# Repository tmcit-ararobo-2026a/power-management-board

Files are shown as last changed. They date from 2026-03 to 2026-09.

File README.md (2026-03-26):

# 電源管理基板
ロボットのバッテリー管理・駆動系電源遮断を行う基板を作成

## 目次

1. [概要](#1-概要)
2. [コントリビューション](#2-コントリビューション)
3. [ライセンス](#3-ライセンス)

## 1. 概要
バッテリー管理コスト削減および駆動系電源遮断を目的とする。
STM32G431K8T6を搭載し、各機能を統括する。

### 機能
- ソフトスタート機能
- 過電圧保護機能
- 電流計測機能
- 制御系・駆動系の絶縁
- 非常停止機能
- バルクコンデンサ

### ソフトスタート機能
突入電流を軽減する目的でソフトスタート機能を実装する。
C2およびR2によって調整される。

100msぐらいで電圧が上昇する計算。
コンデンサの充電時の突入電流を軽減できる。

### 過電圧保護機能
モーターの回生電圧による過電圧時にバッテリーを遮断する。
バッテリーの保護を目的とする。

バルクコンデンサによる軽減および、LM74502QDDFRQ1（過電圧保護機能付き車載用低 IQ 逆極性保護コント
ローラ）による過電圧保護が有効。

過電圧保護は25V前後で働く。
抵抗R3およびR4による分圧で決まる。

### 電流計測機能
バッテリーから出力される電流値を測る。
バッテリーの状態を判断したり、ロボットの総消費電流を分析する目的である。

### 制御系・駆動系の絶縁
制御系と駆動系の絶縁はフォトカプラによって実装。
スイッチ部もSTM32等を保護する観点および、グランドのループを解消する目的で絶縁。

### 非常停止機能
ダブルMOSFETによる完全な駆動系電源遮断を実現。
遠隔非常停止との連携や物理的な非常停止スイッチをJ7/J8間に接続することで非常停止が作動する。

### バルクコンデンサ
モーターの回生電圧を抑え、過渡的な電流上昇時の電源安定を目的とし、2700uFの電解コンデンサを出力部に搭載。

UHE1H272MHDであり、ひとつあたりのリップル電流は3.8Aであるので、合計7.6Aの過渡的な電流増大を軽減できる。

## 2. コントリビューション

[CONTRIBUTING.md](./CONTRIBUTING.md) を参照してください。

## 3. ライセンス

本リポジトリは [MITライセンス](./LICENSE) のもとで公開されています。

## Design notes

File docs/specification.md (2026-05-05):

## 仕様書

バッテリー管理コスト削減および駆動系電源遮断を目的とする電源管理基板である。

### 機能
- ソフトスタート機能
- 過電圧保護機能
- 電流計測機能
- 制御系・駆動系の絶縁
- 非常停止機能
- バルクコンデンサ

### ソフトスタート機能
突入電流を軽減する目的でソフトスタート機能を実装する。
C2およびR2によって調整される。

100msぐらいで電圧が上昇する計算。
コンデンサの充電時の突入電流を軽減できる。

### 過電圧保護機能
モーターの回生電圧による過電圧時にバッテリーを遮断する。
バッテリーの保護を目的とする。

バルクコンデンサによる軽減および、LM74502QDDFRQ1（過電圧保護機能付き車載用低 IQ 逆極性保護コント
ローラ）による過電圧保護が有効。

過電圧保護は25V前後で働く。
抵抗R3およびR4による分圧で決まる。

### 電流計測機能
バッテリーから出力される電流値を測る。
バッテリーの状態を判断したり、ロボットの総消費電流を分析する目的である。

### 制御系・駆動系の絶縁
制御系と駆動系の絶縁はフォトカプラによって実装。
スイッチ部もSTM32等を保護する観点および、グランドのループを解消する目的で絶縁。

### 非常停止機能
ダブルMOSFETによる完全な駆動系電源遮断を実現。
遠隔非常停止との連携や物理的な非常停止スイッチをJ7/J8間に接続することで非常停止が作動する。

### バルクコンデンサ
モーターの回生電圧を抑え、過渡的な電流上昇時の電源安定を目的とし、2700uFの電解コンデンサを出力部に搭載。

UHE1H272MHDであり、ひとつあたりのリップル電流は3.8Aであるので、合計7.6Aの過渡的な電流増大を軽減できる。

### LEDインジケータ
|名称|色|仕様|
|:-:|:-:|:-:|
|LED1|赤|メイン処理ループにて点滅|
|LED2|赤|過電流保護|
|LED3|青|電源供給中|
|LED4|緑|初期化済み（CAN疎通確認）|

### 状態
1. 起動時
遠隔非常停止は無効化され、EMS-INとEMS-OUTを接続することで駆動系はONになる。

2. 遠隔非常停止有効時

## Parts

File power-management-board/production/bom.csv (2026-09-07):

Designator | Footprint | Quantity | Value | LCSC Part #
C10 | 0603 | 1 | 10uf
C11, C12, C13, C14, C19, C20, C21, C25, C26, C5, C6, C7, C8 | 0603 | 13 | 0.1uf
C15, C16, C17, C18 | 0603 | 4 | 1nf
C22 | 0603 | 1 | 0.47uf
C23 | 0603 | 1 | 10nf
C24 | 0603 | 1 | 0.22uf
C3, C4 | CP_Radial_D18.0mm_P7.50mm | 2 | 2700uf
C9 | 0603 | 1 | 1uf
D10, D4, D5, D7, D8, D9 | SOD-123FL | 6 | SS2040FL
D11, D12, D13, D14, D15, D16, D17, D18, D19, D2, D20, D21, D22, D24, D3, D6 | 0603 | 16 | LED
D23, D25, D26, D27, D28 | Diode_US2H | 5 | CUHS20S60
F2 | 0603 | 1 | FCC16501ABTP
IC2 | SOIC127P1105X220-8N | 1 | TLP7820_TP4,E
IC3 | SOIC127P600X175-8N | 1 | MCP2562
IC4 | SOP50P490X110-10N | 1 | LTC4368IMS-2#PBF
J1, J8 | AMASS_XT60-F_1x02_P7.20mm_Vertical | 2 | Conn_01x02
J2, J7 | AMASS_XT60-M_1x02_P7.20mm_Vertical | 2 | Conn_01x02
J3, J4 | JST_XH_S4B-XH-A_1x04_P2.50mm_Horizontal | 2 | Conn_01x04
J5 | PinHeader_1x04_P2.54mm_Vertical | 1 | Conn_01x04_Pin
J6 | TestPoint_2Pads_Pitch2.54mm_Drill0.8mm | 1 | Conn_01x02_Pin
J9 | AMASS_MR30PW-M_1x03_P3.50mm_Horizontal | 1 | Conn_01x03
JP1 | PinHeader_1x02_P2.54mm_Vertical | 1 | jp
Q1, Q2 | XPQR8308QB,LXHQ | 2 | XPQR8308QB,LXHQ
R1, R10, R16, R27, R28, R29, R31, R32, R33, R34, R35, R36, R37, R38, R39, R40, R41, R42, R43, R44, R45, R5, R6, R7, R8, R9 | 0603 | 26 | 1k
R11, R12, R13, R14 | RESC11050X120N | 4 | 100Ω
R15, R19, R22 | 0603 | 3 | 100k
R18, R23, R26, R51, R52 | 0603 | 5 | 10k
R20, R21 | 0603 | 2 | 4.7k
R24 | 0603 | 1 | 120
R25 | 0603 | 1 | 1.6k
R30 | 0603 | 1 | 100
R46, R49 | 0603 | 2 | 2k
R47 | 0603 | 1 | 3k
R48 | 0603 | 1 | 143k
R53 | 0603 | 1 | 22k
RV1, RV2 | Potentiometer_Bourns_3296W_Vertical | 2 | 10k
SW1 | switch_TVAF06-A020B-R | 1 | SW_Push
SW3 | CJS1200A1 | 1 | SW_SPDT_312
TP1, TP2, TP3 | TestPoint_Loop_D1.80mm_Drill1.0mm_Beaded | 3 | TestPoint
U1, U5, U8, U9 | SOIC-4_4.55x2.6mm_P1.27mm | 4 | TLP293
U2 | DIP-6_W7.62mm_SMDSocket_SmallPads | 1 | TLP3546A
U3 | LQFP-32_7x7mm_P0.8mm | 1 | STM32G431K8Tx
U4 | SOT-23-5_HandSoldering | 1 | NJM12888F33
U6 | CZ3A07 | 1 | CZ3A07
U7 | SOT-23_Handsoldering | 1 | AP7375

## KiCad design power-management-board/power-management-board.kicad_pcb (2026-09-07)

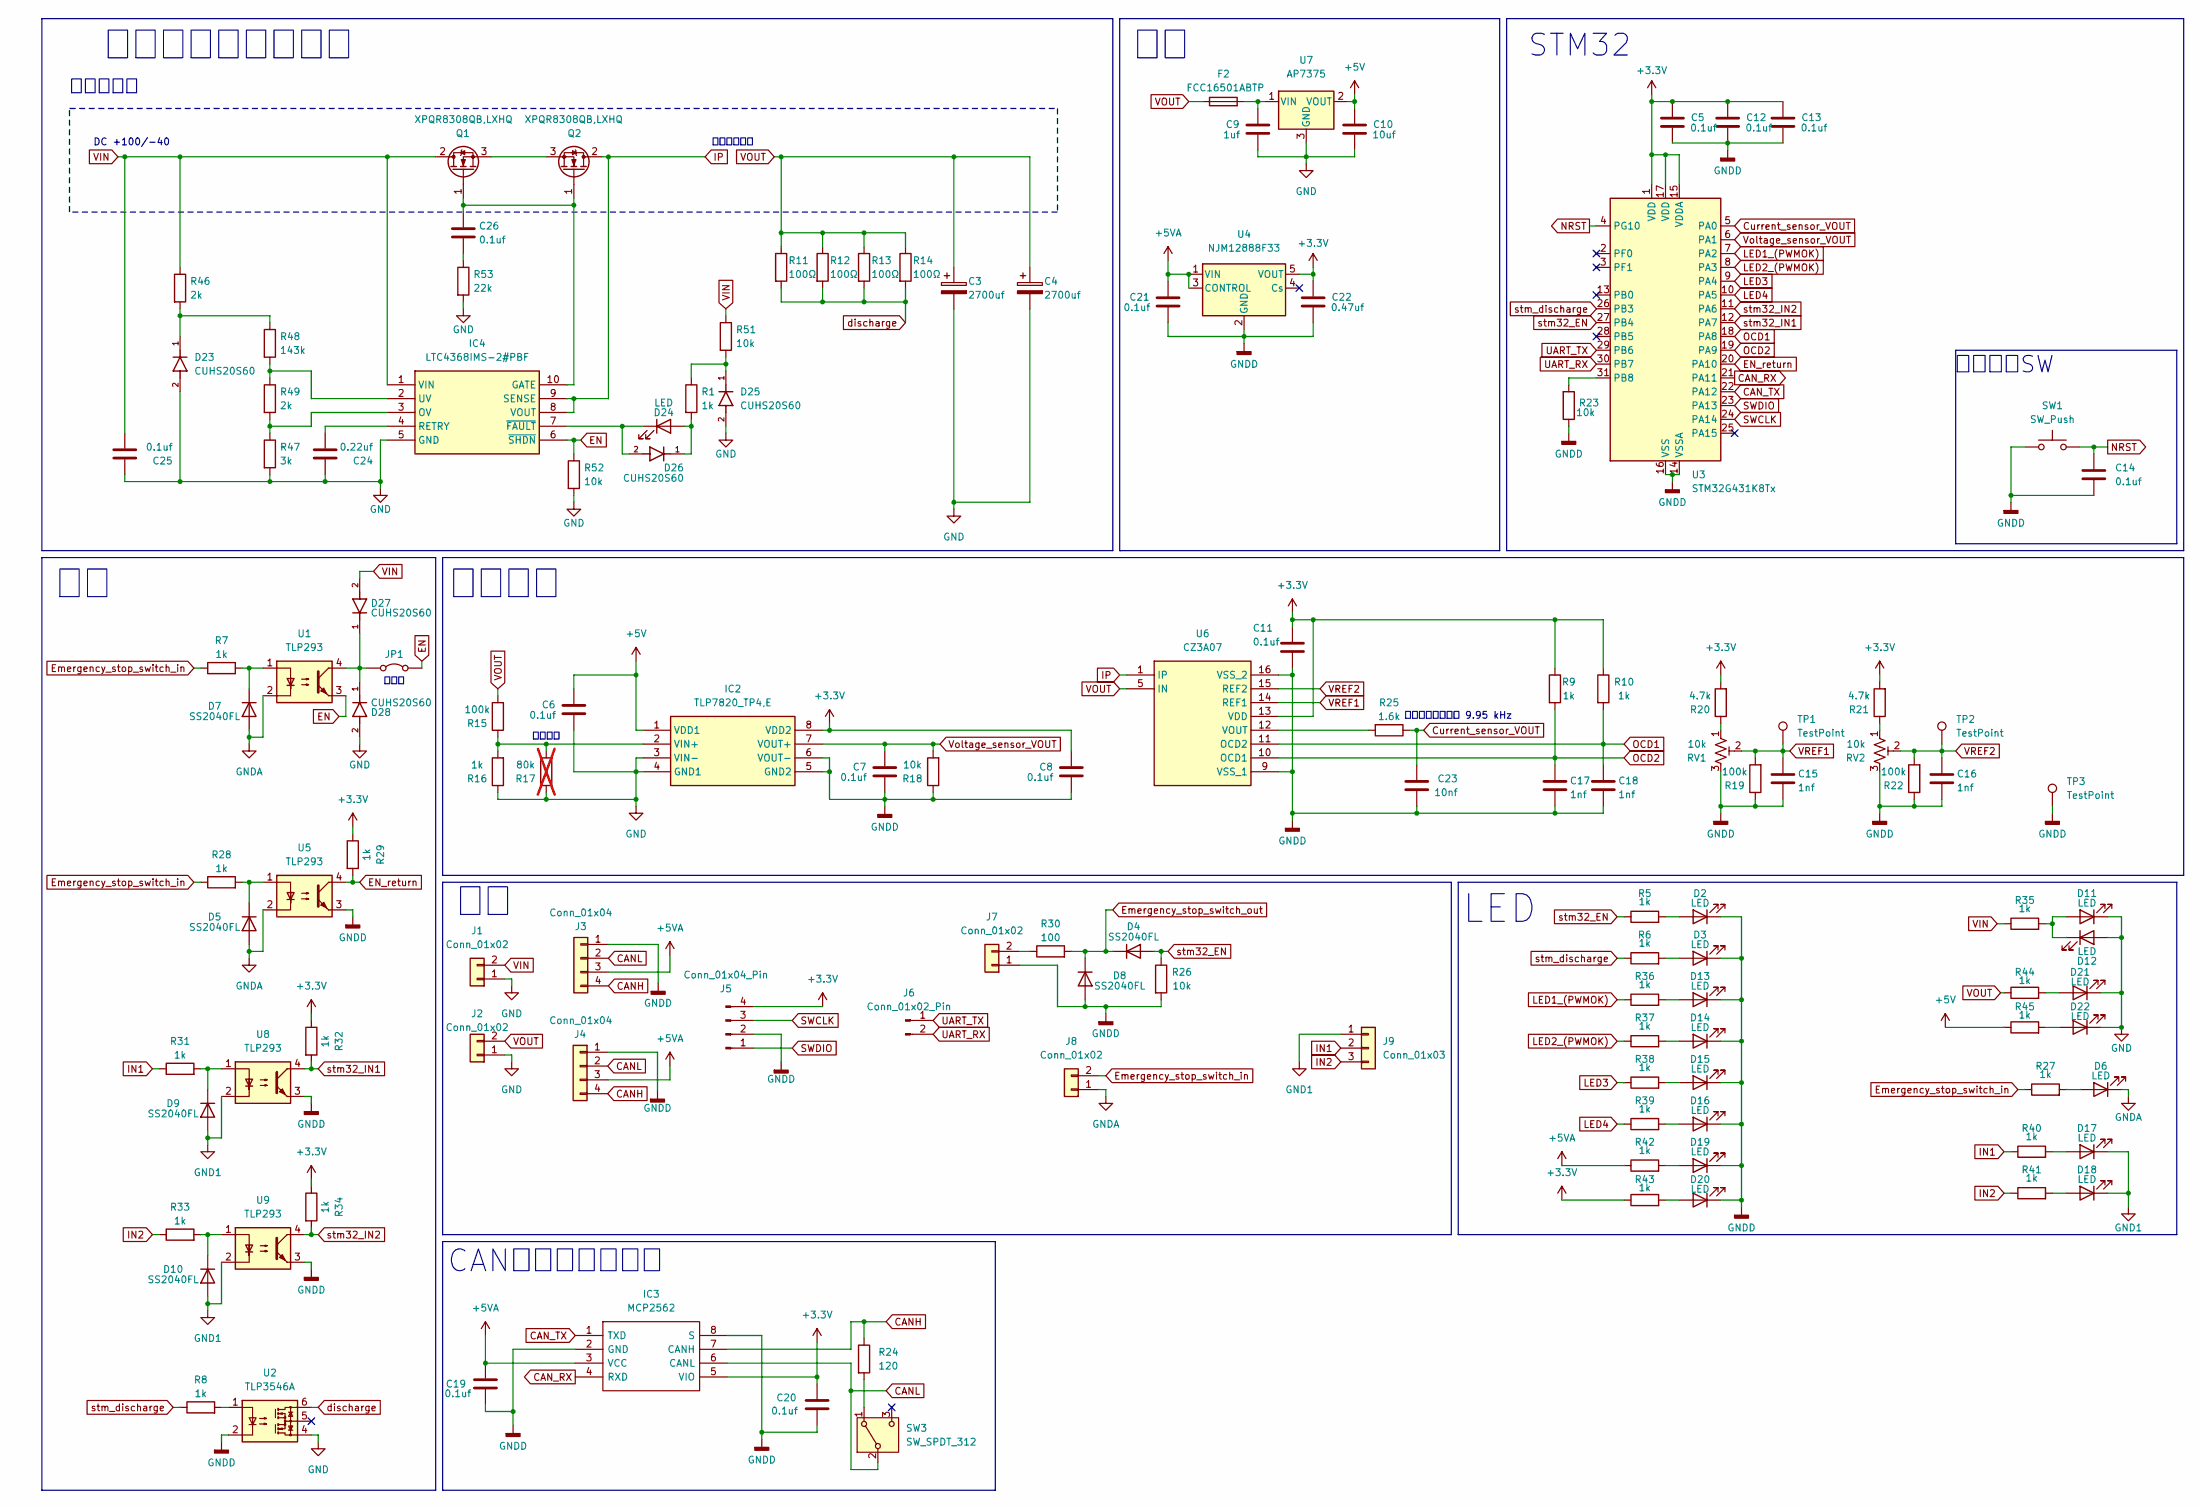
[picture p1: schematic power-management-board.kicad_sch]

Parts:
C3, C4: 2700uf; CP_Radial_D18.0mm_P7.50mm
C5, C6, C7, C8, C11, C12, C13, C14, C19, C20, C21, C25, C26: 0.1uf; C_0603_1608Metric_Pad1.08x0.95mm_HandSolder
C9: 1uf; C_0603_1608Metric_Pad1.08x0.95mm_HandSolder
C10: 10uf; C_0603_1608Metric_Pad1.08x0.95mm_HandSolder
C15, C16, C17, C18: 1nf; C_0603_1608Metric_Pad1.08x0.95mm_HandSolder
C22: 0.47uf; C_0603_1608Metric_Pad1.08x0.95mm_HandSolder
C23: 10nf; C_0603_1608Metric_Pad1.08x0.95mm_HandSolder
C24: 0.22uf; C_0603_1608Metric_Pad1.08x0.95mm_HandSolder
D2, D3, D6, D11, D12, D13, D14, D15, D16, D17, D18, D19, D20, D21, D22, D24: LED; LED_0603_1608Metric_Pad1.05x0.95mm_HandSolder
D4, D5, D7, D8, D9, D10: SS2040FL; SOD-123FL
D23, D25, D26, D27, D28: CUHS20S60; Diode_US2H; PARTREV G
F2: FCC16501ABTP; Fuse_0603_1608Metric_Pad1.05x0.95mm_HandSolder
IC2: TLP7820_TP4,E; SOIC127P1105X220-8N; Manufacturer_Part_Number LM74502QDDFRQ1
IC3: MCP2562; SOIC127P600X175-8N; Mouser Part Number 771-TJA1441AT/0Z
IC4: LTC4368IMS-2#PBF; SOP50P490X110-10N; Mouser Part Number 584-LTC4368IMS2PBF
J1, J8: Conn_01x02; AMASS_XT60-F_1x02_P7.20mm_Vertical
J2, J7: Conn_01x02; AMASS_XT60-M_1x02_P7.20mm_Vertical
J3, J4: Conn_01x04; JST_XH_S4B-XH-A_1x04_P2.50mm_Horizontal
J5: Conn_01x04_Pin; PinHeader_1x04_P2.54mm_Vertical
J6: Conn_01x02_Pin; TestPoint_2Pads_Pitch2.54mm_Drill0.8mm
J9: Conn_01x03; AMASS_MR30PW-M_1x03_P3.50mm_Horizontal
JP1: jp; PinHeader_1x02_P2.54mm_Vertical
Q1, Q2: XPQR8308QB,LXHQ
R1, R5, R6, R7, R8, R9, R10, R16, R27, R28, R29, R31, R32, R33, R34, R35, R36, R37, R38, R39, R40, R41, R42, R43, R44, R45: 1k; R_0603_1608Metric_Pad0.98x0.95mm_HandSolder
R11, R12, R13, R14: 100Ω; RESC11050X120N
R15, R19, R22: 100k; R_0603_1608Metric_Pad0.98x0.95mm_HandSolder
R17: 80k; R_0603_1608Metric_Pad0.98x0.95mm_HandSolder; not fitted
R18, R23, R26, R51, R52: 10k; R_0603_1608Metric_Pad0.98x0.95mm_HandSolder
R20, R21: 4.7k; R_0603_1608Metric_Pad0.98x0.95mm_HandSolder
R24: 120; R_0603_1608Metric_Pad0.98x0.95mm_HandSolder
R25: 1.6k; R_0603_1608Metric_Pad0.98x0.95mm_HandSolder
R30: 100; R_0603_1608Metric_Pad0.98x0.95mm_HandSolder
R46, R49: 2k; R_0603_1608Metric_Pad0.98x0.95mm_HandSolder
R47: 3k; R_0603_1608Metric_Pad0.98x0.95mm_HandSolder
R48: 143k; R_0603_1608Metric_Pad0.98x0.95mm_HandSolder
R53: 22k; R_0603_1608Metric_Pad0.98x0.95mm_HandSolder
RV1, RV2: 10k; Potentiometer_Bourns_3296W_Vertical
SW1: SW_Push; switch_TVAF06-A020B-R
SW3: SW_SPDT_312; CJS1200A1
TP1, TP2, TP3: TestPoint; TestPoint_Loop_D1.80mm_Drill1.0mm_Beaded
U1, U5, U8, U9: TLP293; SOIC-4_4.55x2.6mm_P1.27mm
U2: TLP3546A; DIP-6_W7.62mm_SMDSocket_SmallPads
U3: STM32G431K8Tx; LQFP-32_7x7mm_P0.8mm
U4: NJM12888F33; SOT-23-5_HandSoldering
U6: CZ3A07; Mouser Part Number 412-CZ3A07
U7: AP7375; SOT-23_Handsoldering

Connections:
+3.3V: C5.1, C8.1, C11.1, C12.1, C13.1, C20.1, C22.1, IC2.8 (VDD2), IC3.5 (VIO), J5.4, R9.1, R10.1, R20.2, R21.2, R29.1, R32.1, R34.1, R43.1, U3.1 (VDD), U3.15 (VDDA), U3.17 (VDD), U4.5 (VOUT), U6.13 (VDD)
+5V: C6.1, C10.1, IC2.1 (VDD1), R45.1, U7.2 (VOUT)
+5VA: C19.1, C21.1, IC3.3 (VCC), J3.3, J4.3, R42.1, U4.1 (VIN), U4.3 (CONTROL)
CANH: IC3.7 (CANH), J3.4, J4.4, R24.1
CANL: IC3.6 (CANL), J3.2, J4.2, SW3.2 (B)
CAN_RX: IC3.4 (RXD), U3.21 (PA11)
CAN_TX: IC3.1 (TXD), U3.22 (PA12)
Current_sensor_VOUT: C23.2, R25.1, U3.5 (PA0)
EN: IC4.6 (~SHDN), JP1.2 (B), R52.1, U1.3
EN_return: R29.2, U3.20 (PA10), U5.4
Emergency_stop_switch_in: J8.2, R7.1, R27.1, R28.1
Emergency_stop_switch_out: D4.1 (K), D8.1 (K), R30.2
GND: C3.2, C4.2, C6.2, C9.2, C10.2, C24.1, C25.1, D11.1 (K), D12.2 (A), D21.1 (K), D22.1 (K), D23.2, D25.2, D28.2, IC2.3 (VIN-), IC2.4 (GND1), IC4.5 (GND), J1.1, J2.1, R16.1, R17.1, R47.2, R52.2, R53.2, U2.4, U7.3 (GND)
GND1: D9.2 (A), D10.2 (A), D17.1 (K), D18.1 (K), J9.1, U8.2, U9.2
GNDA: D5.2 (A), D6.1 (K), D7.2 (A), J8.1, U1.2, U5.2
GNDD: C5.2, C7.2, C8.2, C11.2, C12.2, C13.2, C14.2, C15.2, C16.2, C17.2, C18.2, C19.2, C20.2, C21.2, C22.2, C23.1, D2.1 (K), D3.1 (K), D8.2 (A), D13.1 (K), D14.1 (K), D15.1 (K), D16.1 (K), D19.1 (K), D20.1 (K), IC2.5 (GND2), IC2.6 (VOUT-), IC3.2 (GND), IC3.8 (S), J3.1, J4.1, J5.2, J7.1, R18.1, R19.1, R22.1, R23.1, R26.2, RV1.3, RV2.3, SW1.1, TP3.1 (1_1), U2.2, U3.14 (VSSA), U3.16 (VSS), U3.32 (VSS), U4.2 (GND), U5.3, U6.9 (VSS_1), U6.16 (VSS_2), U8.3, U9.3
IN1: J9.2, R31.1, R40.1
IN2: J9.3, R33.1, R41.1
IP: IC4.8 (VOUT), IC4.9 (SENSE), Q2.2 (D), U6.1 (IP)
LED1_(PWMOK): R36.1, U3.7 (PA2)
LED2_(PWMOK): R37.1, U3.8 (PA3)
LED3: R38.1, U3.9 (PA4)
LED4: R39.1, U3.10 (PA5)
NRST: C14.1, SW1.2, U3.4 (PG10)
unnamed: C26.2, R53.1
unnamed: D2.2 (A), R5.2
unnamed: D3.2 (A), R6.2
unnamed: D5.1 (K), R28.2, U5.1
unnamed: D6.2 (A), R27.2
unnamed: D7.1 (K), R7.2, U1.1
unnamed: D9.1 (K), R31.2, U8.1
unnamed: D10.1 (K), R33.2, U9.1
unnamed: D11.2 (A), D12.1 (K), R35.2
unnamed: D13.2 (A), R36.2
unnamed: D14.2 (A), R37.2
unnamed: D15.2 (A), R38.2
unnamed: D16.2 (A), R39.2
unnamed: D17.2 (A), R40.2
unnamed: D18.2 (A), R41.2
unnamed: D19.2 (A), R42.2
unnamed: D20.2 (A), R43.2
unnamed: D21.2 (A), R44.2
unnamed: D22.2 (A), R45.2
unnamed: D23.1, R46.2, R48.1
unnamed: D24.2 (A), D26.1, R1.2
unnamed: D24.1 (K), D26.2, IC4.7 (~FAULT)
unnamed: D25.1, R1.1, R51.2
unnamed: IC2.2 (VIN+), R15.1, R16.2, R17.2
unnamed: C26.1, IC4.10 (GATE), Q1.1 (G), Q2.1 (G)
unnamed: IC4.3 (OV), R47.1, R49.2
unnamed: C24.2, IC4.4 (RETRY)
unnamed: IC4.2 (UV), R48.2, R49.1
unnamed: J7.2, R30.1
unnamed: D27.1, D28.1, JP1.1 (A), U1.4
unnamed: Q1.3 (S), Q2.3 (S)
unnamed: R8.2, U2.1
unnamed: R20.1, RV1.1
unnamed: R21.1, RV2.1
unnamed: R24.2, SW3.1 (A)
unnamed: R23.2, U3.31 (PB8)
unnamed: R25.2, U6.12 (VOUT)
unnamed: C9.1, F2.2, U7.1 (VIN)
OCD1: C18.1, R10.2, U3.18 (PA8), U6.11 (OCD2)
OCD2: C17.1, R9.2, U3.19 (PA9), U6.10 (OCD1)
SWCLK: J5.3, U3.24 (PA14)
SWDIO: J5.1, U3.23 (PA13)
UART_RX: J6.2, U3.30 (PB7)
UART_TX: J6.1, U3.29 (PB6)
VIN: C25.2, D27.2, IC4.1 (VIN), J1.2, Q1.2 (D), R35.1, R46.1, R51.1
VOUT: C3.1, C4.1, F2.1, J2.2, R11.1, R12.1, R13.1, R14.1, R15.2, R44.1, U6.5 (IN)
VREF1: C15.1, R19.2, RV1.2, TP1.1 (1_1), U6.14 (REF1)
VREF2: C16.1, R22.2, RV2.2, TP2.1 (1_1), U6.15 (REF2)
Voltage_sensor_VOUT: C7.1, IC2.7 (VOUT+), R18.2, U3.6 (PA1)
discharge: R11.2, R12.2, R13.2, R14.2, U2.6
stm32_EN: D4.2 (A), R5.1, R26.1, U3.27 (PB4)
stm32_IN1: R32.2, U3.12 (PA7), U8.4
stm32_IN2: R34.2, U3.11 (PA6), U9.4
stm_discharge: R6.1, R8.1, U3.26 (PB3)

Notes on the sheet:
CANトランシーバー
駆動系電源停止回路
高電流区画
DC +100/-40
電流センサー
ローパスフィルタ 9.95 kHz
センサー
非常用
STM32
内部抵抗
LED
リセットSW

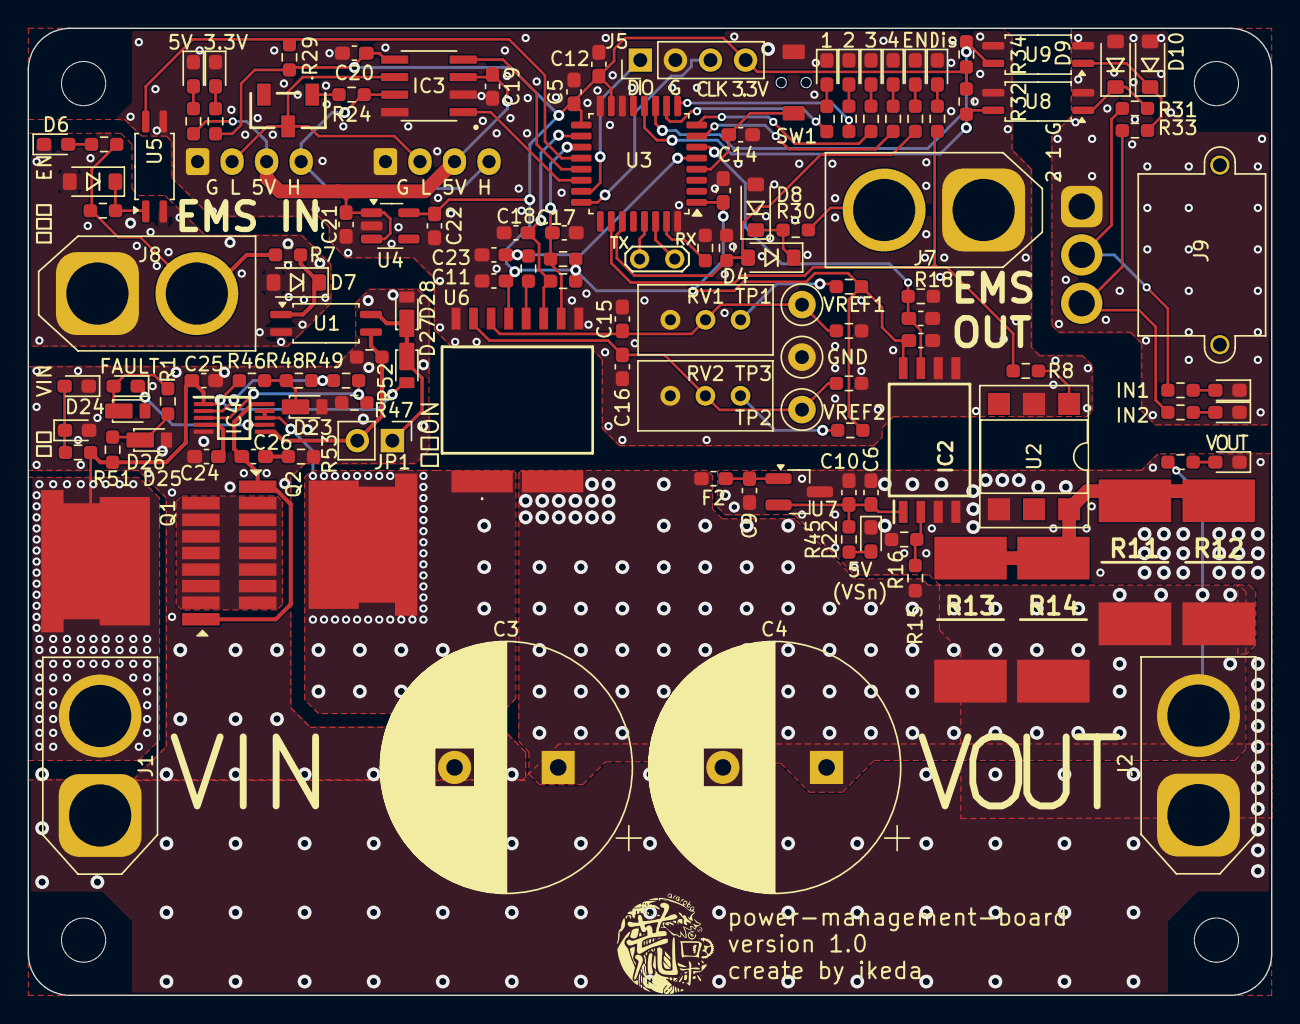
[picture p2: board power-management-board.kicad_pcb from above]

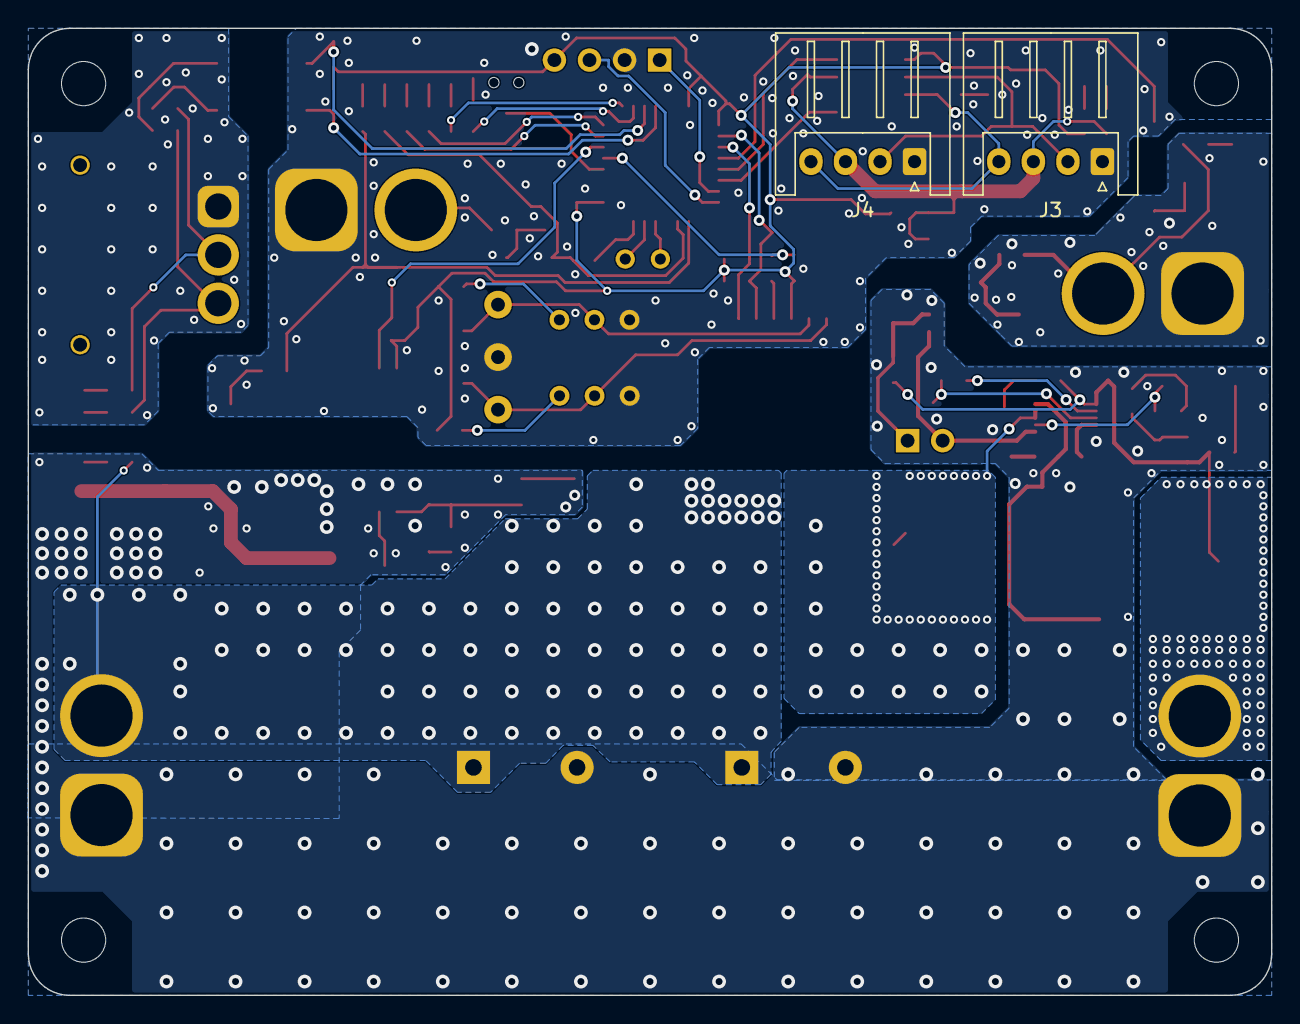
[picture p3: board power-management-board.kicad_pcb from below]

Board: 2 copper layers, 90.0 x 70.0 mm, 131 parts (2 on the bottom side), 78 nets.

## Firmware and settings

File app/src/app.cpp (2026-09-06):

#include "app/app.hpp"

#include <cstdint>

#include "adc.h"
#include "gn10_can/core/fdcan_bus.hpp"
#include "gn10_can/devices/power_manager_server.hpp"
#include "gn10_can/devices/power_manager_types.hpp"
#include "gn10_stm32_fdcan_driver/can_callback_helper.hpp"
#include "gn10_stm32_fdcan_driver/fdcan_driver.hpp"

namespace {
/* パラメータ */
gn10_can::devices::power_manager::Config config{false, 1000};
float conv_voltage = 0.00613573407f;
float conv_current = 0.055f;
int current_offset = 1985;

/* CAN通信用クラス */
gn10_can::drivers::FDCANDriver fdcan_driver(&hfdcan1);
gn10_can::FDCANBus fdcan_bus(fdcan_driver);
gn10_can::devices::PowerManagerServer server(fdcan_bus, 0);

/* フラグやバッファ */
bool initilized = false;
uint16_t adc_raw_value[2];
bool can_stop_signal_enable = false;

/* 前の状態保持 */
gn10_can::devices::power_manager::Status prev_status{false, false, false, false};

/* Hartbeat LED用 */
constexpr uint32_t k_heartbeat_toggle_interval_ms = 500;
uint32_t heartbeat_last_toggle_time_ms            = 0;
/**
 * @brief 一定周期のLEDチカチカ処理
 *
 */
void update_heartbeat_led()
{
    const uint32_t now_ms = HAL_GetTick();
    if ((now_ms - heartbeat_last_toggle_time_ms) >= k_heartbeat_toggle_interval_ms) {
        heartbeat_last_toggle_time_ms = now_ms;
        HAL_GPIO_TogglePin(LED1_GPIO_Port, LED1_Pin);
    }
}

/* センサの送信タイミング調整用 */
uint32_t sensor_last_update_time_ms = 0;
/**
 * @brief センサのデータを取得し正規化した値をCAN通信で送信
 *
 */
void update_sensor()
{
    const uint32_t now_ms = HAL_GetTick();
    if ((now_ms - sensor_last_update_time_ms) >= config.sensor_rate_ms) {
        sensor_last_update_time_ms = now_ms;
        /* 電圧・電流測定 */
        uint16_t current_raw = adc_raw_value[0];
        uint16_t vlotage_raw = adc_raw_value[1];
        float voltage        = vlotage_raw * conv_voltage;
        float current        = float((int)current_raw - current_offset) * conv_current;
        /* CANで送信 */
        gn10_can::devices::power_manager::Sensor sensor_msg;
        sensor_msg.voltage = voltage;
        sensor_msg.current = current;
        server.set_sensor(sensor_msg);
    }
}

}  // namespace

void setup()
{
    fdcan_driver.init();
    if (HAL_ADC_Start_DMA(&hadc1, (uint32_t*)adc_raw_value, 2) != HAL_OK) {
        Error_Handler();
    }
}

void loop()
{
    if (server.get_new_init(config)) {
        initilized = true;
        HAL_GPIO_WritePin(LED4_GPIO_Port, LED4_Pin, GPIO_PIN_SET);
    }

    /* 遠隔非常停止 */
    bool remote_emergency_stop_enable    = false;
    bool remote_emergency_stop_connected = HAL_GPIO_ReadPin(IN1_GPIO_Port, IN1_Pin);
    // 0Vのとき遠隔非常停止を有効化
    if (HAL_GPIO_ReadPin(IN2_GPIO_Port, IN2_Pin)) {
        remote_emergency_stop_enable = false;
    } else {
        remote_emergency_stop_enable = true;
    }
    // 遠隔非常停止機能を使わない場合は遠隔非常停止を無効化
    if (!config.use_remote_emergency_stop) {
        remote_emergency_stop_enable = false;
    }

    /* CAN通信経由の非常停止信号受信 */
    server.get_new_stop(can_stop_signal_enable);
    if (can_stop_signal_enable) {
        HAL_GPIO_WritePin(LED3_GPIO_Port, LED3_Pin, GPIO_PIN_SET);
    } else {
        HAL_GPIO_WritePin(LED3_GPIO_Port, LED3_Pin, GPIO_PIN_RESET);
    }

    /* 遠隔非常停止＆CAN通信経由非常停止を反映 */
    bool logical_stop_enable = can_stop_signal_enable || remote_emergency_stop_enable;
    if (logical_stop_enable) {
        HAL_GPIO_WritePin(EMS_EN_OUT_GPIO_Port, EMS_EN_OUT_Pin, GPIO_PIN_RESET);
    } else {
        HAL_GPIO_WritePin(EMS_EN_OUT_GPIO_Port, EMS_EN_OUT_Pin, GPIO_PIN_SET);
    }

    /* 電源遮断回路への信号を監視して放電回路を動作 */
    bool emergency_stop_enabled =
        HAL_GPIO_ReadPin(EMS_EN_IN_GPIO_Port, EMS_EN_IN_Pin) == GPIO_PIN_SET;
    if (emergency_stop_enabled) {  // 負論理
        // 駆動系OFF
        HAL_GPIO_WritePin(DISCHARGE_GPIO_Port, DISCHARGE_Pin, GPIO_PIN_SET);
    } else {  // 駆動系ON
        HAL_GPIO_WritePin(DISCHARGE_GPIO_Port, DISCHARGE_Pin, GPIO_PIN_RESET);
    }

    /* 過電流保護 */
    bool over_current =
        HAL_GPIO_ReadPin(OCD1_GPIO_Port, OCD1_Pin) || HAL_GPIO_ReadPin(OCD2_GPIO_Port, OCD2_Pin);

    /* Status送信 */
    gn10_can::devices::power_manager::Status status{};
    status.emergency_stop_enabled          = emergency_stop_enabled;
    status.remote_emergency_stop_connected = remote_emergency_stop_connected;
    status.remote_emergency_stop_enabled   = remote_emergency_stop_enable;
    status.over_current                    = over_current;
    if (status != prev_status) {
        server.set_status(status);
        prev_status = status;
    }

    update_sensor();
    update_heartbeat_led();
}

extern "C" {
// C言語側の関数のオーバーライド
/**
 * @brief Receive callback for FDCAN FIFO0.
 */
void HAL_FDCAN_RxFifo0Callback(FDCAN_HandleTypeDef* hfdcan, uint32_t RxFifo0ITs)
{
    (void)RxFifo0ITs;
    if (process_fdcan_fifo(hfdcan, &hfdcan1, fdcan_bus, FDCAN_RX_FIFO0)) return;
}

/**
 * @brief Receive callback for FDCAN FIFO1.
 */
void HAL_FDCAN_RxFifo1Callback(FDCAN_HandleTypeDef* hfdcan, uint32_t RxFifo1ITs)
{
    (void)RxFifo1ITs;
    if (process_fdcan_fifo(hfdcan, &hfdcan1, fdcan_bus, FDCAN_RX_FIFO1)) return;
}
}

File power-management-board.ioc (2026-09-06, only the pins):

Mcu.UserName=STM32G431K8Tx
PA0.Signal=ADC1_IN1
PA1.Signal=ADC1_IN2
PA10.GPIO_Label=EMS_EN_IN
PA10.Signal=GPIO_Input
PA11.Signal=FDCAN1_RX
PA12.Signal=FDCAN1_TX
PA13.Signal=SYS_JTMS-SWDIO
PA14.Signal=SYS_JTCK-SWCLK
PA2.GPIO_Label=LED4
PA2.Signal=GPIO_Output
PA3.GPIO_Label=LED3
PA3.Signal=GPIO_Output
PA4.GPIO_Label=LED2
PA4.Signal=GPIO_Output
PA5.GPIO_Label=LED1
PA5.Signal=GPIO_Output
PA6.GPIO_Label=IN2
PA6.Signal=GPIO_Input
PA7.GPIO_Label=IN1
PA7.Signal=GPIO_Input
PA8.GPIO_Label=OCD1
PA8.Signal=GPIO_Input
PA9.GPIO_Label=OCD2
PA9.Signal=GPIO_Input
PB3.GPIO_Label=DISCHARGE
PB3.Signal=GPIO_Output
PB4.GPIO_Label=EMS_EN_OUT
PB4.Signal=GPIO_Output
PB6.Signal=USART1_TX
PB7.Signal=USART1_RX

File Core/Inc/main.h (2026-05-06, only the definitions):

#define LED4_Pin GPIO_PIN_2
#define LED4_GPIO_Port GPIOA
#define LED3_Pin GPIO_PIN_3
#define LED3_GPIO_Port GPIOA
#define LED2_Pin GPIO_PIN_4
#define LED2_GPIO_Port GPIOA
#define LED1_Pin GPIO_PIN_5
#define LED1_GPIO_Port GPIOA
#define IN2_Pin GPIO_PIN_6
#define IN2_GPIO_Port GPIOA
#define IN1_Pin GPIO_PIN_7
#define IN1_GPIO_Port GPIOA
#define OCD1_Pin GPIO_PIN_8
#define OCD1_GPIO_Port GPIOA
#define OCD2_Pin GPIO_PIN_9
#define OCD2_GPIO_Port GPIOA
#define EMS_EN_IN_Pin GPIO_PIN_10
#define EMS_EN_IN_GPIO_Port GPIOA
#define DISCHARGE_Pin GPIO_PIN_3
#define DISCHARGE_GPIO_Port GPIOB
#define EMS_EN_OUT_Pin GPIO_PIN_4
#define EMS_EN_OUT_GPIO_Port GPIOB

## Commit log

2026-03-21 回路図完成
    [power-management-board.kicad_pcb, power-management-board.kicad_sch]
2026-03-22 修正版(非常停止はあとで変更します)
    [power-management-board.kicad_pcb, power-management-board.kicad_sch]
2026-03-23 修正版完成
    [power-management-board.kicad_sch]
2026-03-23 仮配置完了
    [power-management-board.kicad_pcb, power-management-board.kicad_sch]
2026-03-24 完成(ビア以外)
    [power-management-board.kicad_pcb, power-management-board.kicad_sch]
2026-03-25 docs:仕様書追加
2026-04-02 ガーバー
    [bom.csv, designators.csv, positions.csv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]
2026-04-03 fix:わかりにくいリファレンス番号を消し、OVOFFなどパット見でわからない言葉を一般化、シルクの隙間を作り可読性向上
    [power-management-board.kicad_pcb]
2026-04-07 feat:add upstream base-stm32
2026-04-19 feat:ファームウェア作成のためiocファイル追加。ADC設定は途中。
2026-04-28 feat:電流・電圧測定のためADC設定。DMAを有効化してCPU負荷を低減し安定したサンプリングを考えた。
2026-04-28 feat:初期コード生成
2026-04-28 feat:数kHzでサンプリングできれば十分なのでスキャン周期を遅くした
2026-04-28 feat:app用ライブラリ追加
2026-04-28 feat:gn10_can追加
2026-04-28 feat:メイン処理関数追加
2026-04-28 feat:canの割り込みを有効化してNVIC優先順位を下げた
2026-04-28 fix:.history消去
2026-04-28 chore:gitignoreに.historyを追加
2026-04-28 chore:バックアップファイルを除外
2026-04-28 feat:gn10-canを電源管理デバイスの実装があるブランチにチェックアウト
2026-04-28 feat:FDCAN用ドライバ追加
2026-04-28 feat:adc処理をベタ書き
2026-05-05 feat:printfできるように実装し、floatの表示を設定
2026-05-05 feat:adc設定見直し、DMAのリクエストを連続変換モードへ統一
2026-05-05 feat:adc設定
2026-05-05 feat:vscode用書き込みタスクを追加
2026-05-05 feat:ハードウェアで遊んだ
2026-05-05 feat:[WIP]メイン処理を少し実装
2026-05-05 feat:センサの周期をTickで管理
2026-05-05 refactor:変数の配置を整え、パラメータへのアクセス性を向上
2026-05-05 fix:電流に電圧を代入していたので修正
2026-05-05 chore:gn10-canをmainへ切り替え
2026-05-06 fix:ledのピン配置が逆転していたので修正
2026-05-06 feat:遠隔非常停止とCAN通信からの停止処理追加
2026-05-06 fix:EN_INは負論理
2026-05-06 chore:gn10-can更新
2026-05-06 refactor:初期化追加
2026-05-06 fix:fdcanに変更
2026-05-08 feat:遠隔非常停止機能対か
2026-05-08 chore:gn10-canをmainにチェックアウト
2026-05-08 feat:過電流保護の有無をStatusに対か
2026-05-09 fix:gn10-can実装のstatus構造体の比較演算子にバグがあったので修正
2026-05-09 feat:Delay関数はリアルタイム性に欠けるため排除
2026-05-09 docs:余白整理・パラメータを明記
2026-09-01 feat:gn10-can修正
2026-09-01 feat:can通信のseg調整
2026-09-02 feat:gn10-canの修正
2026-09-03 feat:CANDriver更新
2026-09-03 feat:appに修正
2026-09-03 feat:canライブラリ追加
2026-09-03 fix:driverに合わせて修正
2026-09-06 LM74502QDDFRQ1からLTC4368IMS2PBFに変更
    [power-management-board.kicad_pcb, power-management-board.kicad_sch]
2026-09-07 抵抗の計算完了、常時ONのジャンパーPINの追加
    [power-management-board.kicad_pcb, power-management-board.kicad_sch]
2026-09-07 ガーバの生成
    [bom.csv, designators.csv, positions.csv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]
2026-09-15 feat:電圧補正
2026-09-15 feat:gn10-can更新
2026-09-15 refactor:計算式を明記、タイプミス修正
2026-09-15 feat:CANの割り込み優先度を下げた
2026-09-15 feat:MCUのADC基準電圧を設けて論理的に機差補正
2026-09-16 feat:キャリブレーション入れる
2026-10-13 リレーversion(v2)の回路設計完了PCBはこれから
2026-10-13 feat:ゲートに抵抗追加＆常時ON削除
2026-10-14 シルク調整、DRC通した
2026-10-14 ガーバ生成
2026-10-22 feat:リレー駆動用のコードに変更
2026-10-22 feat:コンデンサ充電と電源供給のデッドタイム追加

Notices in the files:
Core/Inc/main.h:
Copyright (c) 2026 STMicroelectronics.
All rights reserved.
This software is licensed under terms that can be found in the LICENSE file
